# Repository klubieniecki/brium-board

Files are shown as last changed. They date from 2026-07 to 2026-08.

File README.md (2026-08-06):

<p align="center">
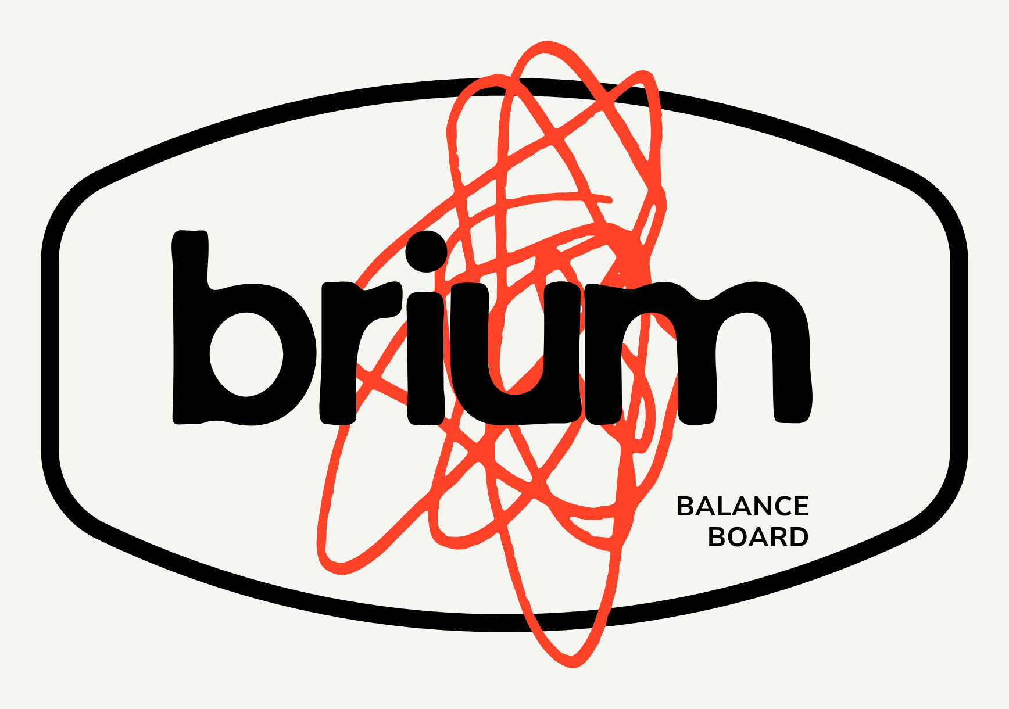
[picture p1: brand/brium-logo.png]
Brium Board
  
</p>

# Brium Board

*Brium* — the tail of *equilibrium*.

A rocker-style balance board and stand, cut from a **single 2 ft × 2 ft plywood
sheet** (610 × 610 mm), balanced on a lacrosse ball.

The board profile, the stand and the ball guard all come from **[dtxtr's
"Balance Board Stand (board and ball)"](https://www.printables.com/model/1341613-balance-board-stand-board-and-ball)**
on Printables. What this repo adds is the piece that model doesn't include: a
**3D-printed stencil** that lays the cut line out on your plywood — correctly
scaled to a 2×2 sheet, symmetric by construction, and drawn from one printed
template that works at all four corners.

<!-- IMAGE still needed: hero shot — finished board on the stand, ball underneath,
     good light. When shot, save as docs/images/finished-board.jpg and restore:
![The finished Brium board](docs/images/finished-board.jpg) -->

---

## What you make

| Part | Material | Source |
| --- | --- | --- |
| Brium board | 12 mm plywood, 360 × 610 mm | cut it yourself — **this repo's stencil** |
| Stand | 3D printed | `stl/brium_stand.stl` — remixed from [dtxtr's design](https://www.printables.com/model/1341613-balance-board-stand-board-and-ball) |
| Ball guard | 12 mm plywood | [dtxtr on Printables](https://www.printables.com/model/1341613-balance-board-stand-board-and-ball) — cut from the offcut |
| Ball | lacrosse ball | any sporting goods shop |

Everything printed here is a **jig**, not a part of the finished board. Once the
plywood is cut, the stencil's job is done.

---

## Bill of materials

| Item | Spec | Notes |
| --- | --- | --- |
| Plywood | 610 × 610 × 12 mm | 2 ft × 2 ft hobby panel. Birch ply is what the original used; void-free matters more than species |
| Lacrosse ball | [standard](https://www.amazon.ca/dp/B072373GWG), ~63 mm | solid rubber. Do not substitute a tennis ball |
| Filament | ~40 g for the stencil, ~150 g per stand piece | PLA is fine for both |
| 3 mm rod | 40 mm | joins the two stencil halves. A stub of 1.75 mm filament doubled over, an M3 bolt, or a brad nail all work |
| Sandpaper | 80 / 120 / 220 grit | |
| Finish | oil, poly or hardwax | your call |

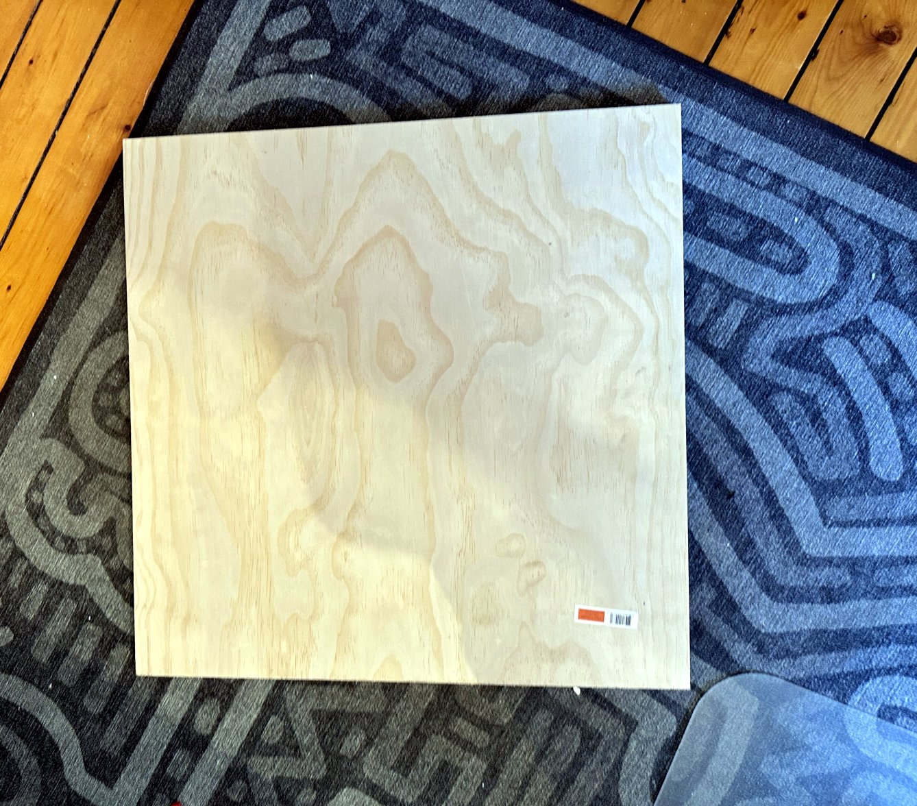
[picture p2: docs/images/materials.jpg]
The 610 × 610 sheet, before anything happens to it


---

## The cut

Your sheet is 610 × 610. Rip it once:

```
┌─────────────────────────── 610 ───────────────────────────┐
│                                                           │
│   BOARD          360 mm wide × 610 mm long                │  610
│                                                           │
├───────────────────────────────────────────────────────────┤
│   OFFCUT         250 mm × 610 mm  →  ball guard           │
└───────────────────────────────────────────────────────────┘
```

The board keeps the **full 610 mm length** of the sheet and gets ripped to
**360 mm wide**. The 250 mm offcut is more than enough for the ball guard.

The rounded outline is then laid out **inside** that 360 × 610 rectangle — it
touches all four edges, so you lose nothing to the curve.

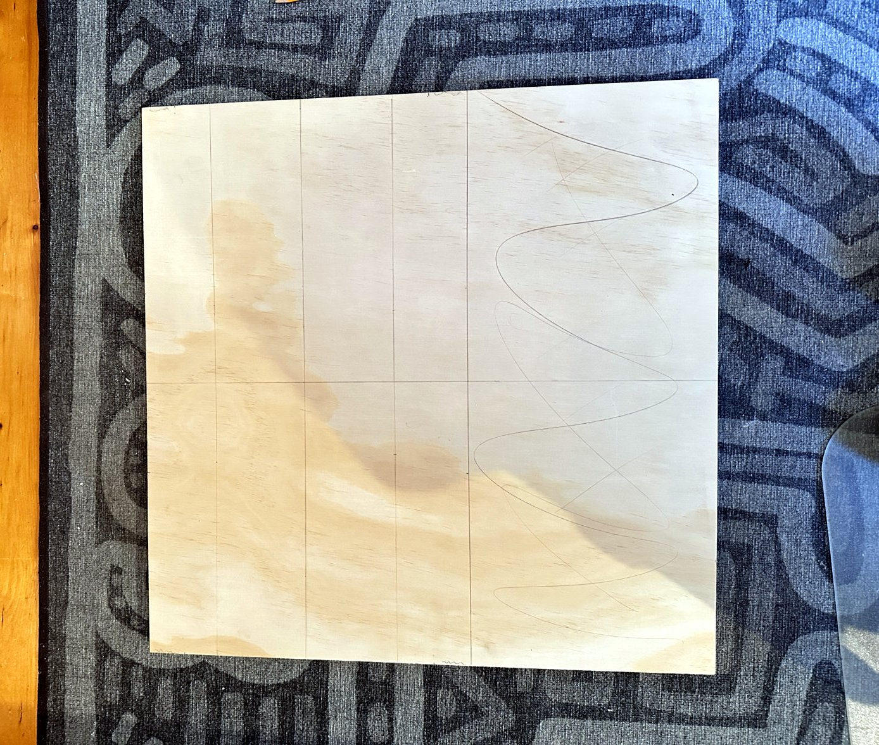
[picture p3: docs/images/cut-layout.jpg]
The sheet marked up — centrelines and layout before the rip cut


---

## The geometry

dtxtr's profile is a 540 × 310 outline built from four elements per side: a
straight flat on each short end, a tight corner radius, and one long sweep arc
down each side. Scaled to a 2×2 sheet:

| Element | dtxtr's original (540 × 310) | This build (610 × 360) |
| --- | --- | --- |
| Overall length | 540 mm | **610 mm** (full sheet) |
| Overall width | 310 mm | **360 mm** |
| Straight flat, each short end | 110 mm | **128 mm** |
| Corner radius | R50 | **R60** |
| Long sweep radius | R559 | **R623.94** |
| Sweep centre, below the long centreline | 404 mm | **443.94 mm** |
| Arcs meet tangent at | — | **(271.1, 118.0)** |

The sweep radius is **not a free choice.** It is solved so the long arc is
tangent to the corner arc *and* peaks exactly on the board edge at mid-length:

```
R = ( (L − rc)² + (W − a)² − rc² ) / ( 2 · (W − a − rc) )

L  = 305   half length        a  = 64   half the end flat
W  = 180   half width         rc =  60   corner radius
```

That is what keeps the outline fair — no visible kink where the corner meets
the sweep. Change the end flat or the corner radius in the .scad and the sweep
re-solves itself.

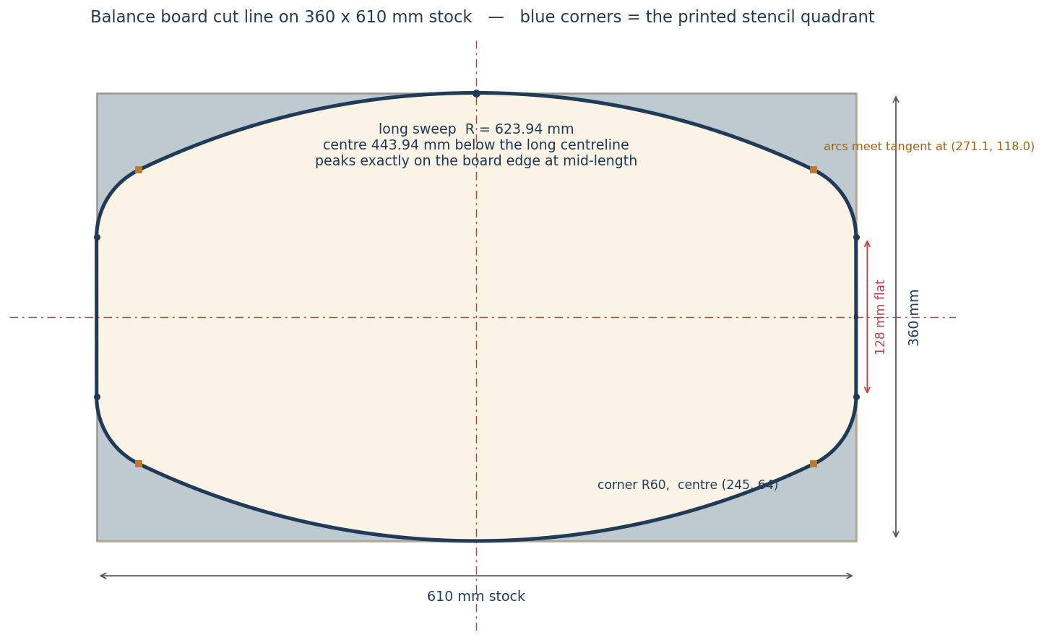
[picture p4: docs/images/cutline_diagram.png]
Cut line on a 360 × 610 sheet


---

## The stencil

The printed part is the **waste crescent** between the board corner and the cut
line — the material you're about to remove. It's a rib frame: a 9 mm rib
hugging the cut line (the edge you trace against), a 6 mm flange along each
board edge, and three cross ribs.

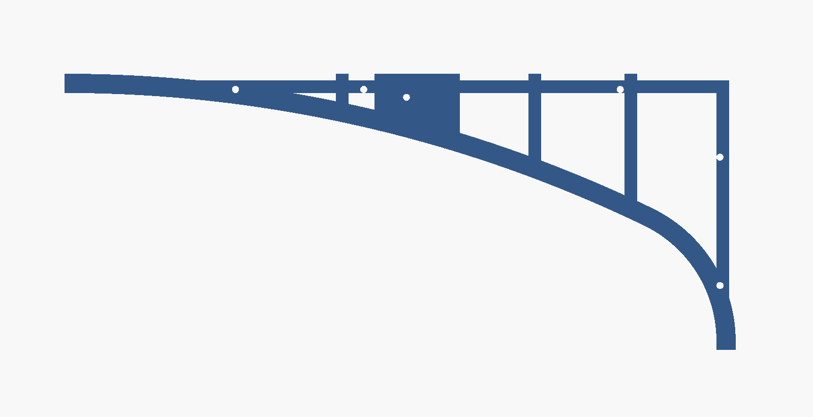
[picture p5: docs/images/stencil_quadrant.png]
Stencil quadrant


### One template, four corners

The outline is symmetric about both centrelines, so the *shape* at every corner
is identical. A quadrant isn't mirror-symmetric though — two corners want it
left-handed, two want it right-handed. A flat part handles that by flipping
over, so the stencil registers **both ways up**:

| Corner | Orientation | How it locates |
| --- | --- | --- |
| top-right | lip down | flanges hook the plywood corner |
| bottom-left | lip down, rotated 180° | same |
| top-left | flipped, lip up | pegs dropped into the flange holes |
| bottom-right | flipped, rotated 180° | same |

**Lip down** — the flanges hang 6 mm past the board edges and drop 3 mm. Seat
it on a corner and it hooks both edges. It can only sit in one place.

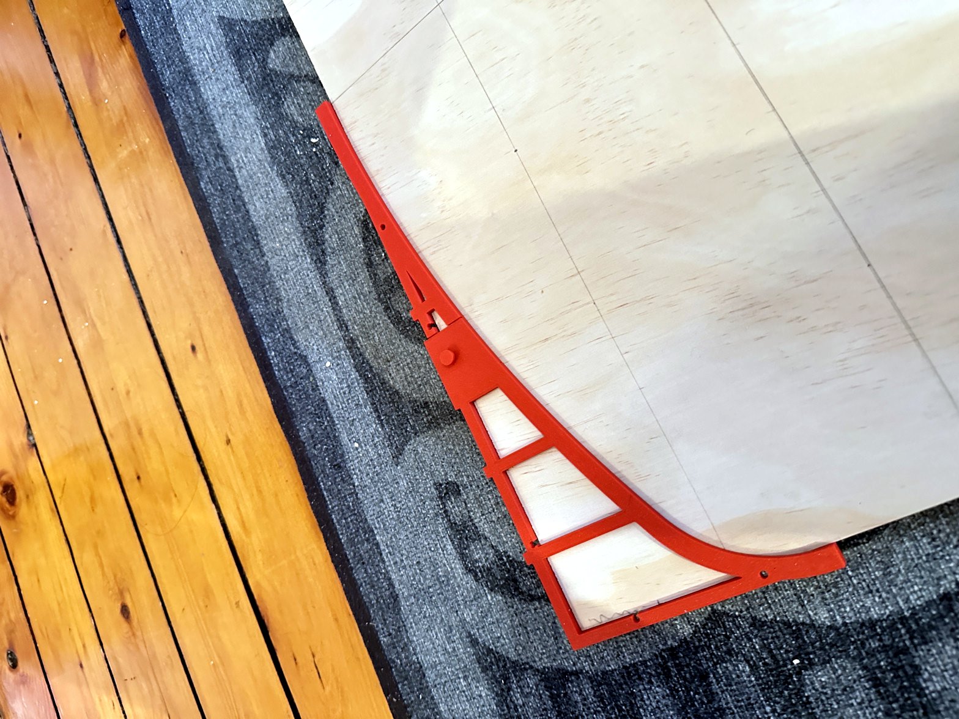
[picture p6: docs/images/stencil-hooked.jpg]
Lip down, hooked over the plywood corner


**Flipped** — the lip now faces up and hooks nothing, so five loose pegs take
over. Their holes are placed so the **inner tangent of the peg sits exactly on
the board edge line**, and a through-hole is symmetric about the plate's
mid-plane, so the registration survives the flip.

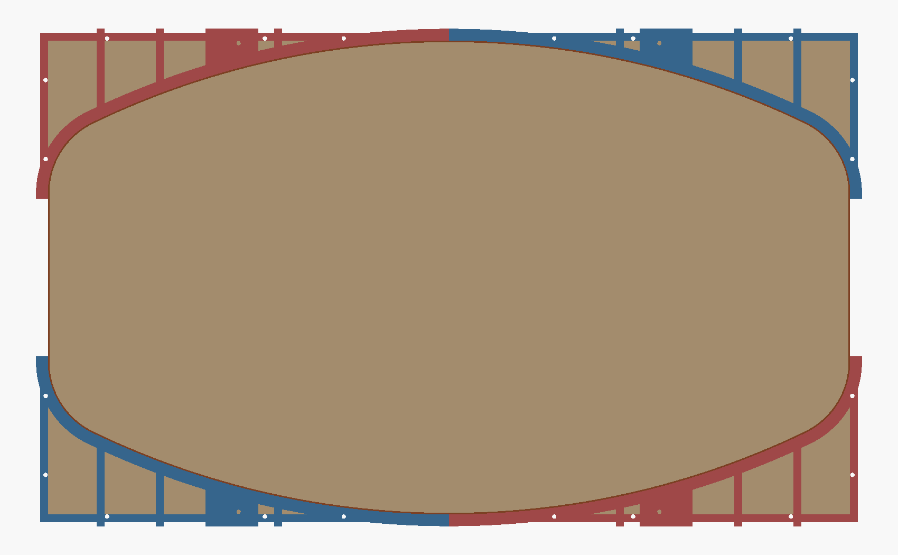
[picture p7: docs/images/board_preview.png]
All four corners


### Using it

1. Mark both centrelines on the plywood — mid-length and mid-width.
2. Lip down, hook the stencil over a corner, both flanges hard against the
   edges. **Check:** the straight edge at the mid-length end should land on your
   centreline. If it does, the geometry is right.
3. Trace the inner curved edge.
4. Rotate 180° for the opposite corner.
5. Flip the stencil, press the pegs in, seat them against the board edges, and
   do the remaining two corners.
6. The short ends need no tracing — the cut line runs along the existing edge
   for 128 mm before it curves away.

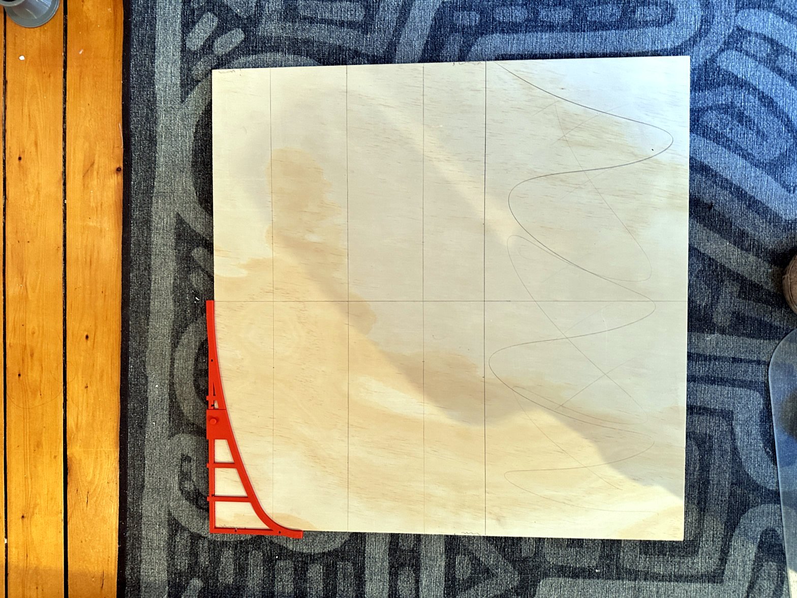
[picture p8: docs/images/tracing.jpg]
The stencil seated on a corner, ready to trace


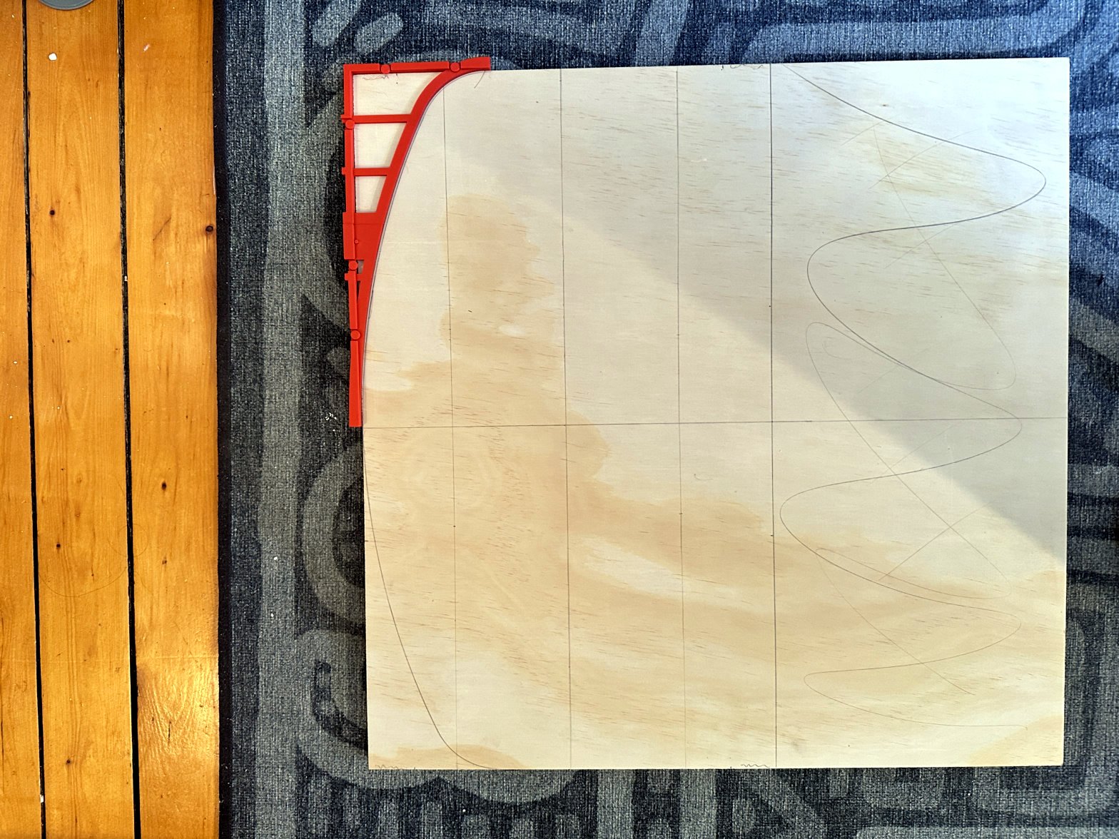
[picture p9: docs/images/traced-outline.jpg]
Flipped for the opposite-handed corners, outline taking shape


### Cutting and finishing

Jigsaw or bandsaw just outside the line, then sand back to it. A spindle sander
or a drum in a drill press makes short work of the R60 corners. Round the top
edges over with a 3–6 mm roundover or just break them with 120 grit — you'll be
standing on this barefoot.

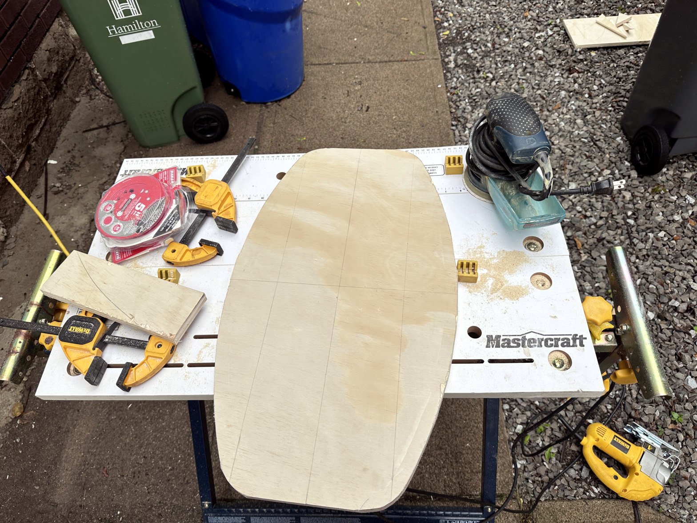
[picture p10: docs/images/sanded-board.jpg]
Cut and sanded, before finish


---

## Printing

### The stencil (this repo)

| File | Size | Notes |
| --- | --- | --- |
| `stl/brium_stencil_end.stl` | 169 × 129 × 7 mm | corner half — the R60 and most of the sweep |
| `stl/brium_stencil_mid.stl` | 175 × 34 × 7 mm | reaches the board's mid-length |
| `stl/brium_stencil_pegs.stl` | 8 pegs | print a couple spare |
| `brium_stencil.3mf` | — | ready-to-slice Bambu Studio project, all plates set up |

Flat on the bed, **no supports**. The plate prints first and the lip rail on
top of it, so nothing overhangs — flip each piece over to use it. Pegs print
head-down. Everything fits a 180 mm bed.

The two halves join with a half-lap and a 3 mm pin. Glue is optional; the pin
plus the lap is enough for a jig.

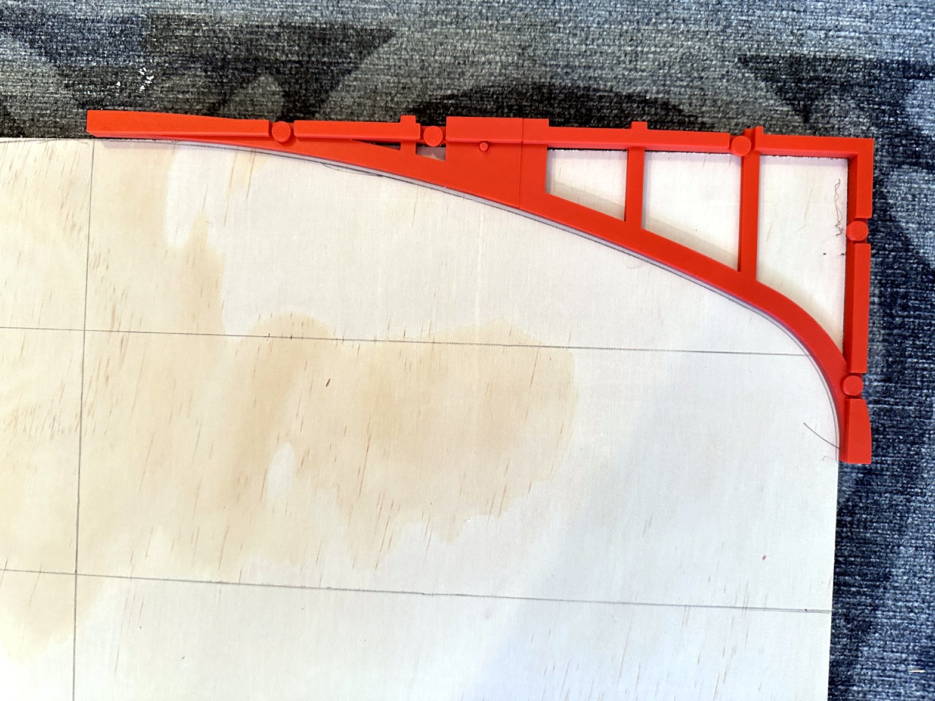
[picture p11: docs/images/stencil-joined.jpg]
Both halves joined, sitting on the traced line


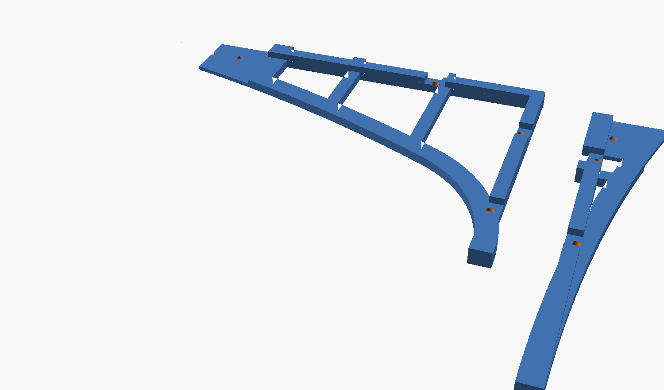
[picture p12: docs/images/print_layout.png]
Print layout


### The stand

**A remix of [dtxtr's stand](https://www.printables.com/model/1341613-balance-board-stand-board-and-ball)**,
modified to suit this build. His original is the design; this is a derivative
of it — go download and like his model too.

| File | Size | Notes |
| --- | --- | --- |
| `stl/brium_stand.stl` | 103 × 130 × 24 mm | one stand piece — print two |
| `brium_stand.3mf` | — | Bambu Studio project, sliced for a P1S |

125 cm³ of geometry, so budget roughly 150 g of filament per piece. The 3mf is
set up at 0.2 mm layers, 2 walls, 15 % infill, **no supports**, auto brim.

The stand is sized for 12 mm board stock — keep your plywood at 12 mm or adjust
the model to suit.

### The ball guard

Plywood, not printed — cut it from the 250 mm offcut. Dimensions are on
[dtxtr's page](https://www.printables.com/model/1341613-balance-board-stand-board-and-ball).

### The original Rola parts

Further up the family tree sits
**[whitespring's "Balance board pattern and parts"](https://www.printables.com/model/926271-balance-board-pattern-and-parts)**.
Their `Rola_Parts-v2.3mf` (two printed parts, ready-sliced in PrusaSlicer) is
included unmodified in [`third_party/whitespring/`](third_party/whitespring/) —
see that folder's README and their Printables page for usage and licence.

They mount to the board's underside with threaded inserts and M-screws:

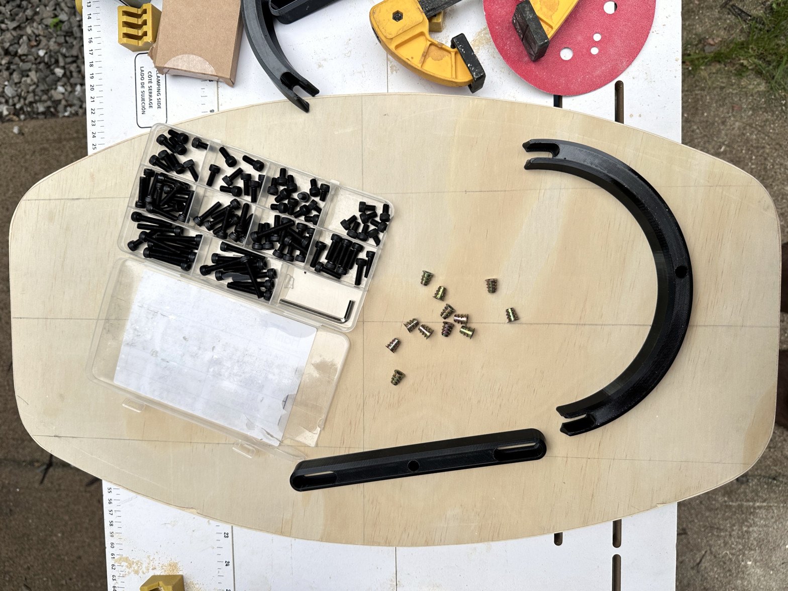
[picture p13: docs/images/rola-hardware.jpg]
Inserts, screws and the printed Rola parts


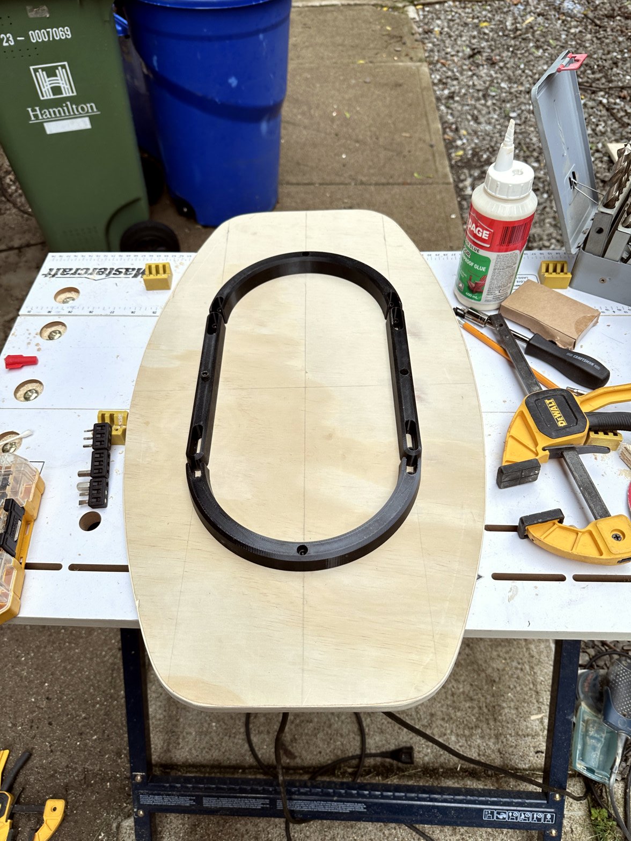
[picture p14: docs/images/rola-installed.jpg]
The Rola guard track installed on the underside


---

## Customising

Everything lives in `brium_stencil.scad`. Open it in
[OpenSCAD](https://openscad.org/), or use Window → Customizer for a form.

| Parameter | Default | Effect |
| --- | --- | --- |
| `BOARD_LEN` / `BOARD_WID` | 610 / 360 | your stock size — everything re-solves |
| `END_FLAT` | 128 | longer flat = squarer ends, flatter sweep |
| `CORNER_R` | 60 | tighter corners = more aggressive nose |
| `OVERHANG` / `LIP_T` | 6 / 3 | flange width past the edge, and lip depth |
| `PEGS` | true | peg holes for the flipped orientation |
| `TRACE_RIB` / `RIB_W` / `RIB_X` | 9 / 6 / 3 ribs | frame proportions |
| `PLATE_T` | 4 | plate thickness |
| `SPLIT_X` | 175 | where the two halves meet — lower it for a small bed |
| `PENCIL_COMP` | 0 | set to your pencil-tip radius (~0.7) so the drawn line lands on the true curve |
| `LIGHTEN` | true | rib frame vs solid crescent |

Re-export with:

```bash
./export_stl.sh
```

On macOS the OpenSCAD binary is inside the app bundle, which the script handles.
Set `PART` to `print_end`, `print_mid` or `pegs` if you'd rather export by hand
— **not** `assembly`, which is the two halves mated at 319 mm.

Deeper notes on the geometry, the joint and the mesh gotchas are in
[`docs/stencil.md`](docs/stencil.md).

---

## Repo layout

```
brium_stencil.scad     the parametric source — everything comes from here
export_stl.sh                  regenerates all three STLs
brium_stencil.3mf      Bambu Studio project, ready to slice
stl/                           exported meshes
third_party/whitespring/       whitespring's original Rola parts, unmodified
docs/stencil.md                design notes: geometry, joint, mesh validation
docs/images/                   renders and build photos
site/                          the landing site (Next.js, deploys on Vercel)
```

---

## Credits

- **[whitespring](https://www.printables.com/@whitespring)** — the
  [Balance board pattern and parts](https://www.printables.com/model/926271-balance-board-pattern-and-parts)
  ("Rola") that this whole family of boards traces back to. Their printed Rola
  parts are included unmodified in
  [`third_party/whitespring/`](third_party/whitespring/) — go like the
  original.
- **[dtxtr](https://www.printables.com/@dtxtr_339032)** — the original
  [Balance Board Stand (board and ball)](https://www.printables.com/model/1341613-balance-board-stand-board-and-ball).
  The board profile, the stand and the ball guard are all his design. This repo
  re-derives his outline for a different sheet size, wraps it in a layout jig,
  and includes a modified version of his stand. If you build this, go give his
  model a like first.
- Brium stencil design and OpenSCAD source:
  **[@klubieniecki](https://github.com/klubieniecki)**

## License

<!-- Pick one and delete the rest. CC BY-SA 4.0 is the usual choice for
     printable models and keeps you compatible with the remix culture on
     Printables/MakerWorld. -->

The OpenSCAD source and the exported **stencil** files in this repo are released
under **CC BY-SA 4.0**.

`brium_stand.stl` / `brium_stand.3mf` are a **derivative of dtxtr's stand**, not
original work. Before publishing this repo or a listing, check that his licence
permits derivatives and redistribution, and match whatever terms he set.

Everything under `third_party/` is **other people's work, included unmodified**
(currently whitespring's Rola parts) and is *not* covered by this repo's
licence — the terms on each original model page apply.

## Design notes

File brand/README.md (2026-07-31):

# Brium Board — brand assets

## Logo

`brium-logo.png` is the logo. The badge outline is the **real board profile** —
the same 610 × 360 cut line the stencil draws, at 12 px weight.

| File | Use |
| --- | --- |
| `brium-logo.png` | primary — README header, listings, print |
| `brium-logo-square.png` | same logo on a square canvas — avatars, thumbnails |
| `brium-logo-transparent.png` | background knocked out |

The logo is **raster**. That's fine for GitHub, MakerWorld and Printables, but
if you ever need it large-format or laser-engraved you'll want it as vector —
the badge outline below is already vector, so it's only the type and the
scribble that would need redrawing.

The type and the scribble are black, so **the transparent version needs a light
background**. On dark it disappears. Use the light background version, or
recolour before you put it on anything dark.

## Board outline

The bare cut-line shape, black stroke, no fill. This is what the badge in the
logo is built from.

| File | Weight |
| --- | --- |
| `brium-board-outline-3px.svg` | hairline |
| `brium-board-outline-5px.svg` | light |
| `brium-board-outline-8px.svg` | medium |
| `brium-board-outline-10px.svg` | heavy |
| `brium-board-outline-12px.svg` | heaviest — the weight used in the logo |

Coordinates are **1 unit = 1 mm**, so the SVG is natively 610 × 360 and
dimensionally accurate. Generated by `outline.py` — add any weight you want to
the tuple and re-run.

Note the stroke straddles the path, so at 12 px the drawn shape reads ~6 px
larger on every side than the true cut line. Don't trace one of these at 1:1;
that's what the stencil is for.

## Palette

| | Hex | Use |
| --- | --- | --- |
| Ink | `#000000` | outline, wordmark |
| Flare | `#FF4A24` | the scribble |
| Paper | `#F6F5EF` | background |

## Earlier exploration

`brium-mark*.svg`, `brium-avatar*.svg`, `brium-wordmark.svg` and
`brium-logo-horizontal/stacked.svg` are an earlier direction — the board
silhouette crossing a sun, generated by `build.py`. Superseded by the logo
above, kept in case any of it is useful for stickers or a secondary mark.

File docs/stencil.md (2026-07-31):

# Brium Board — stencil design notes

> Build guide and materials list: [../README.md](../README.md)

A parametric OpenSCAD stencil for laying out the rounded cut line of a balance
board on **360 × 610 mm** plywood (36 × 61 cm), derived from the Printables
["Balance Board Stand Board and Ball"](https://www.printables.com/model/1341613-balance-board-stand-board-and-ball)
sketch.

One printed quadrant marks all four corners.

---

## The geometry

The reference sketch is a 540 × 310 outline built from four elements per side:

| Element | Reference (540 × 310) | Yours (610 × 360) |
| --- | --- | --- |
| Overall length | 540 mm | **610 mm** (full stock) |
| Overall width | 310 mm | **360 mm** (full stock) |
| Straight flat on each short end | 110 mm | **128 mm** |
| Corner radius | R50 | **R60** |
| Long-side sweep radius | R559 (solved) | **R623.94 (solved)** |
| Sweep centre, below the long centreline | 404 mm | **443.94 mm** |
| Arcs meet tangent at | (271.1, 118.0) equivalent | **(271.1, 118.0)** |

The sweep radius is not a free choice. It is solved so the long arc is
simultaneously **tangent to the corner arc** and **peaks exactly on the board
edge at mid-length**:

```
R = ( (L - rc)² + (W - a)² - rc² ) / ( 2 · (W - a - rc) )

L  = 305  half length          a  = 64  half the end flat
W  = 180  half width           rc =  60  corner radius
```

That single formula is what keeps the whole outline smooth — no visible kink
where the corner meets the long sweep. Change `END_FLAT` or `CORNER_R` in the
.scad and the sweep re-solves itself.

Origin is the centre of the board. The cut line leaves the short end edge at
**y = ±64 mm** and touches the long edge at **x = 0**.

---

## How the stencil works

The printed part is the *waste crescent* between the board corner and the cut
line — the material you will be cutting away.

Trace along the inner curved edge.

### Registration — and why one template does all four corners

The outline is symmetric about both centrelines, so the *shape* at every corner
is the same. But a quadrant is not mirror-symmetric: two corners want it
left-handed, two want it right-handed. A flat part handles that — you flip it
over. The only thing that can break the flip is a feature living on one face,
which is exactly what a moulded lip is. So the template carries both:

| Corner | Orientation | Registration |
| --- | --- | --- |
| top-right | lip down | flanges hook the plywood corner |
| bottom-left | lip down, rotated 180° | same |
| top-left | flipped (lip up) | drop pegs into the flange holes |
| bottom-right | flipped, rotated 180° | same |

**Lip down** — the flanges hang 6 mm past the board edges and drop 3 mm. Seat
it on the corner and it hooks both edges; it can't sit anywhere else. No
measuring, no squaring up.

**Flipped** — the lip now faces up and hooks nothing, so the pegs take over.
Their holes are positioned so the **inner tangent of the peg lies exactly on
the board edge line**. A through-hole is symmetric about the plate's
mid-plane, so this survives the flip. Five holes: three along the long edge
(x = 80, 140, 260) and two along the short end (y = 90, 150). Three would
locate it; five means you can skip one if a clamp is in the way.

The lip is interrupted by a 10 mm gap at each peg hole — partly so the hole
isn't tangent to the lip's inner face (that made the export non-manifold),
partly to give the peg head somewhere flat to sit.

### Filament

A rib frame, not a solid plate: a 9 mm rib hugging the cut line, a 6 mm flange
strip along each board edge, three cross ribs, and a solid patch at the joint.
Everything else is open.

| | Solid, lipped, 15 mm flange | Lean rib frame |
| --- | --- | --- |
| Corner piece | 74.3 cm³ | **20.7 cm³** |
| Mid piece | 25.7 cm³ | **11.9 cm³** |
| 8 pegs | — | **1.2 cm³** |
| Copies needed for 4 corners | 2 (one mirrored) | **1** |
| **Total** | **200 cm³** | **33.8 cm³** (−83%) |

Ribs only pay where the frame is actually open. Below about x = 105 the trace
rib and the flange merge into one bar, so ribs there were doing nothing — the
count went 5 → 3 for that reason, not to shave grams.

Levers if you want less still: `TRACE_RIB` 9 → 8 (−1.5 cm³, but the pencil
edge gets narrow), `PLATE_T` 4 → 3.5 (the half-lap tongue is already only
1.8 mm — I would not). `LIGHTEN = false` goes back to the solid crescent.

### Printing

The quadrant is 319 × 129 mm, so it is half-lapped into two pieces that pin
together with a 3 mm rod (or a stub of filament) through the joint.

| Piece | Size | Notes |
| --- | --- | --- |
| `print_end` | 169 × 129 × 7 mm | the corner half, does the R60 and most of the sweep |
| `print_mid` | 175 × 34 × 7 mm | the thin half that reaches the board's mid-length |
| `pegs` | 8 buttons, 44 × 20 | registration pegs, print a couple spare |

Print **flat on the bed, no supports** — the plate goes down first and the lip
rail prints on top of it, so nothing overhangs. Flip each piece over to use it.
Pegs print head-down. Everything fits a 180 mm bed.

Do not export `PART = "assembly"` — that is the two pieces mated, 319 mm long.

#### Exporting the STLs

`./export_stl.sh` writes the whole print set to `stl/` as binary STLs:

| File | What it is |
| --- | --- |
| `brium_stencil_end.stl` | the corner half of the template |
| `brium_stencil_mid.stl` | the half that reaches the board's mid-length |
| `brium_stencil_pegs.stl` | 8 registration pegs |

Three prints, all four corners. All watertight, single-body, correct winding —
Bambu Studio imports them without a repair prompt. Or by hand: set `PART` to
`print_end` / `print_mid` / `pegs`, F6, then File → Export → Export as STL.

For a 180 mm bed, raise `FLANGE_Y0` (currently 30) to about 60, or move
`SPLIT_X` down to ~155.

Render targets (`PART = ...`):

| Value | Shows |
| --- | --- |
| `assembly` | both pieces joined — the full quadrant |
| `print_end` / `print_mid` | one piece, ready to export as STL |
| `print_all` | both laid out for a 220 × 220 bed |
| `board_preview` | the stock, the cut line, and all four stencils in place |
| `outline_only` | the raw 2D cut line (export as DXF/SVG for a 1:1 paper template) |

### Using it

1. Mark the two centrelines on the plywood (mid-length and mid-width).
2. Lip down, hook the template over a corner — both flanges hard against the
   board edges. The straight edge at the mid-length end should land on your
   centreline; that is your check that the geometry is right.
3. Trace the inner curve. Set `PENCIL_COMP` to your pencil-tip radius
   (≈ 0.7 mm) if you want the drawn line to land dead on the true curve.
4. Rotate 180° for the opposite corner. For the remaining two, flip the
   template over, press the pegs in, and seat them against the board edges.
5. The short ends are already straight — the cut line runs along the existing
   edge for 128 mm before it curves away.

---

## Parameters worth touching

| Parameter | Default | Effect |
| --- | --- | --- |
| `END_FLAT` | 128 | longer flat = squarer ends, flatter sweep |
| `CORNER_R` | 60 | tighter corners = more aggressive nose |
| `OVERHANG` / `LIP_T` | 6 / 3 | flange width past the edge, and lip depth |
| `PEGS` | true | peg holes for the flipped orientation |
| `TRACE_RIB` / `RIB_W` / `RIB_X` | 9 / 6 / 3 ribs | frame proportions |
| `PEG_X` / `PEG_Y` | lists | where the registration pegs sit |
| `LIGHTEN` | true | rib frame instead of a solid crescent |
| `PLATE_T` | 4 | plate thickness |
| `SPLIT_X` | 175 | where the two pieces meet |
| `PENCIL_COMP` | 0 | grows the curve by the pencil-tip radius |
| `MIRROR` | false | mirrored copy for the other two corners |

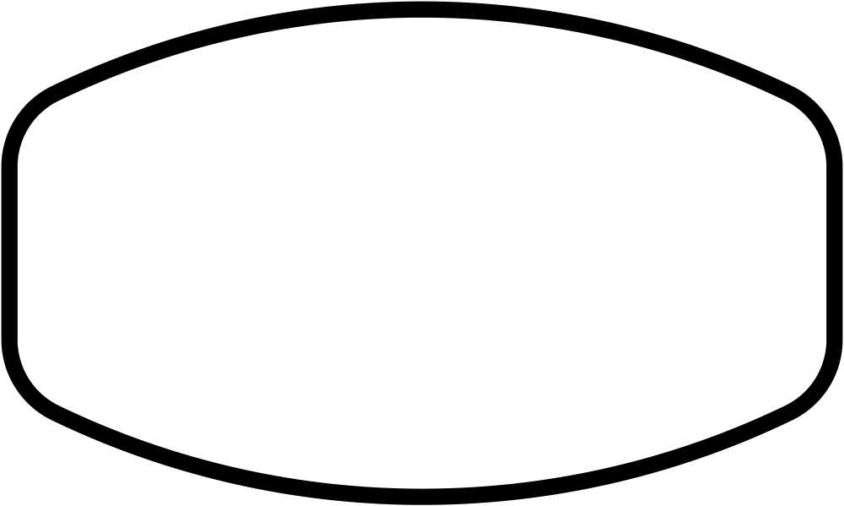
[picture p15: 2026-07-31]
brand/brium-board-outline-12px.png

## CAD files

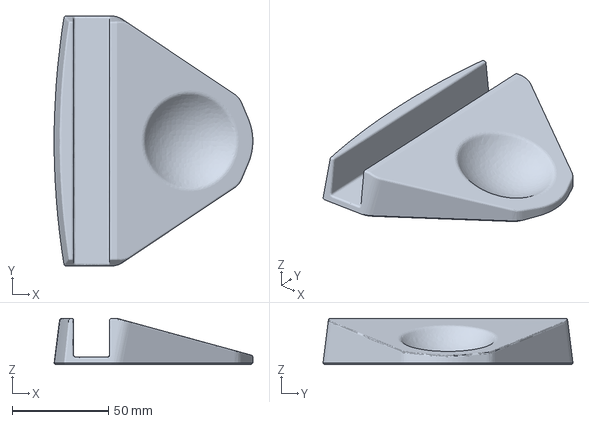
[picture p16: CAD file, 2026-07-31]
brium_stand.3mf
103.2 x 129.8 x 24.0 mm

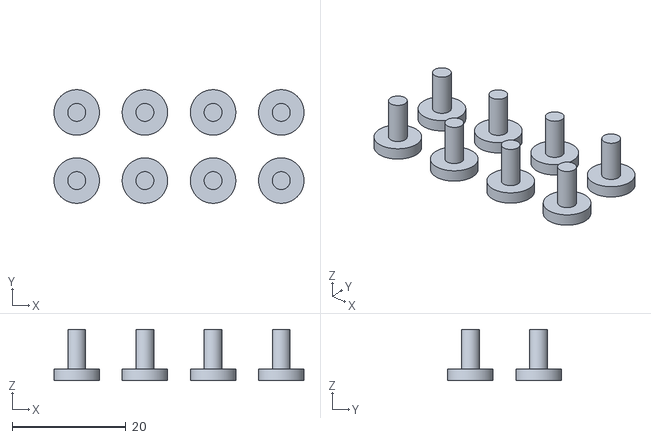
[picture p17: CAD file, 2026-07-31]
stl/brium_stencil_pegs.stl
44.0 x 20.0 x 9.00

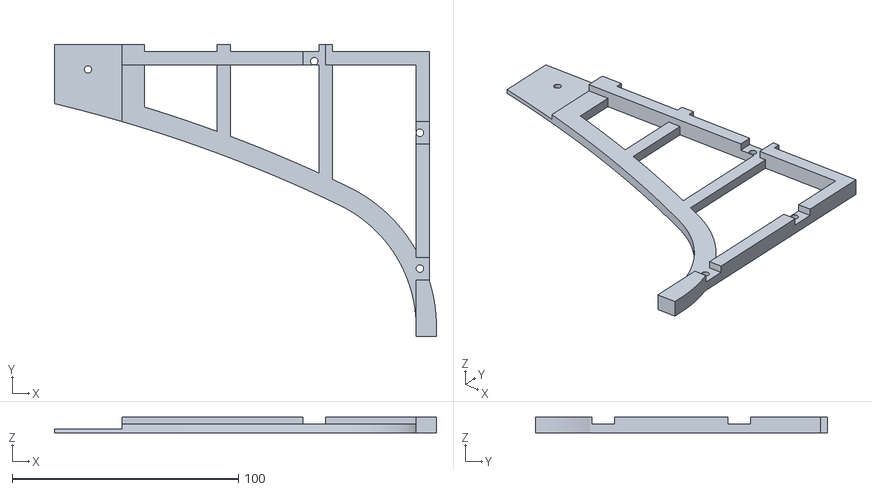
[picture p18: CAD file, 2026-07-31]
stl/brium_stencil_end.stl
168.8 x 129.0 x 7.00

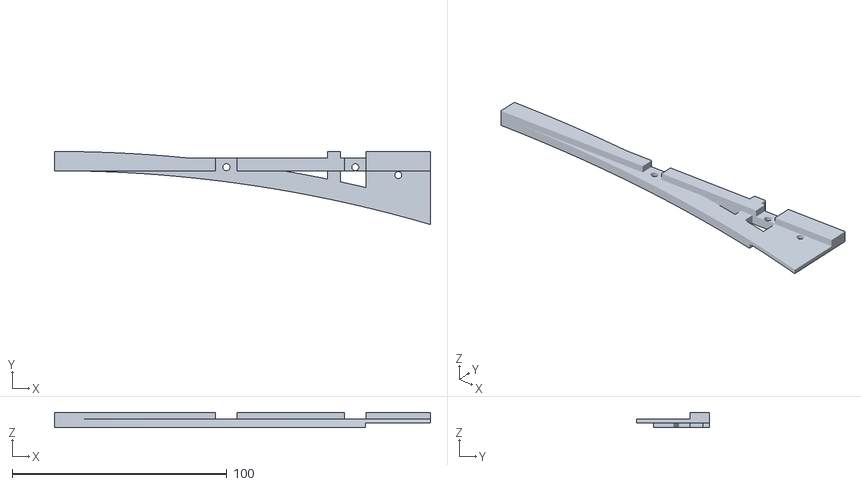
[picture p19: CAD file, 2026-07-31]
stl/brium_stencil_mid.stl
175.0 x 34.0 x 7.00

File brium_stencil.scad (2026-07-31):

// =====================================================================
// Brium Board - outline stencil, ONE QUADRANT, all four corners
// ---------------------------------------------------------------------
// Stock       : 360 mm x 610 mm plywood (36 cm x 61 cm)
// Shape source: Printables "Balance Board / Stand Board and Ball"
//               sketch = 540 x 310, 110 mm end flat, R50 corners.
//               Re-solved here so the cut line touches all four edges
//               of YOUR board and stays tangent everywhere.
//
// The stencil is a rib frame sitting in the WASTE crescent between the board
// corner and the cut line. Trace the inner curved edge.
//
// Registration, two corners at a time:
//
//   Lip down  - the flanges hang 6 mm past the board edges and drop 3 mm, so
//               the template hooks the plywood corner and cannot sit anywhere
//               else. Covers corner (+,+) and, rotated 180 deg, (-,-).
//   Flipped   - the lip now faces up and cannot hook anything, so drop loose
//               pegs into the flange holes instead. Their inner tangent lies
//               exactly on the board edge line, and a through hole is
//               symmetric about the plate's mid-plane, so the registration
//               survives the flip. Covers the other two corners.
//
// One template, four corners, no mirrored second copy.
// =====================================================================

$fn = 200;

/* [Board] */
BOARD_LEN   = 610;   // long dimension of the plywood (mm)
BOARD_WID   = 360;   // short dimension of the plywood (mm)
END_FLAT    = 128;   // straight run left on each short end (mm)
CORNER_R    = 60;    // radius of the four tight corners (mm)

/* [Stencil body] */
OVERHANG    = 6;     // flange width past the board edge
FLANGE_Y0   = 60;    // end-edge flange starts here (raise for a smaller bed)
PLATE_T     = 4;     // plate thickness
LIP_T       = 3;     // how far the flange drops over the board edge (0 = flat plate)
MIRROR      = false; // true -> mirrored copy for the other two corners
PENCIL_COMP = 0;     // pencil-tip radius, e.g. 0.7 -> line lands on the true curve

/* [Lightening] */
LIGHTEN     = true;  // false -> old solid crescent
TRACE_RIB   = 9;     // width of the rib that hugs the cut line
RIB_W       = 6;     // width of the cross ribs
RIB_X       = [130, 220, 265];  // where the cross ribs sit

/* [Reversible registration] */
PEGS        = true;  // peg holes for the flipped orientation, where the lip
                     // faces up and cannot hook the board
PEG_D       = 3.3;   // peg hole dia; inner tangent sits on the board edge
PEG_X       = [80, 140, 260];  // peg holes along the long edge
PEG_Y       = [90, 150];       // peg holes along the short end edge
PEG_HEAD_D  = 8;     // peg head
PEG_HEAD_T  = 2;
PEG_STAND   = 3;     // how far the peg stands proud on the underside
PEG_FIT     = 0.15;  // shaft undersize for a press fit
PEG_NOTCH   = 10;    // width of the gap cut in the lip at each peg hole
PEG_COUNT   = 8;     // how many to lay out in PART = "pegs"

/* [Splitting for the print bed] */
SPLIT       = true;  // half-lap the quadrant into two printable pieces
SPLIT_X     = 175;   // joint position, measured from board centre
LAP_LEN     = 30;    // half-lap overlap length
LAP_TOL     = 0.2;   // fit clearance
JOINT_PAD   = 10;    // how far the solid joint patch runs past the split plane
PIN_D       = 3.2;   // vertical alignment pin (3 mm filament / M3 rod)
PIN_Y       = 178;   // where the pin goes

/* [What to render] */
// assembly | print_end | print_mid | pegs | print_all | board_preview | outline_only
PART        = "assembly";

// ---------------------------------------------------------------------
// derived geometry
// ---------------------------------------------------------------------
L  = BOARD_LEN / 2;   // 305  half length
W  = BOARD_WID / 2;   // 180  half width
A  = END_FLAT  / 2;   //  64  half of the straight end run
RC = CORNER_R;

// Long-side sweep radius, solved so that arc is tangent to the corner
// arc AND peaks exactly on the board edge at mid-length.
SWEEP_R = (pow(L - RC, 2) + pow(W - A, 2) - pow(RC, 2)) / (2 * (W - A - RC));
CY      = W - SWEEP_R;                  // sweep centre (well below the board)
CCX     = L - RC;                       // corner arc centre
CCY     = A;
THETA_T = atan2(CCY - CY, CCX);         // tangent angle, measured at the sweep centre
TX      = SWEEP_R * cos(THETA_T);
TY      = CY + SWEEP_R * sin(THETA_T);

echo(str("--- cut line ---"));
echo(str("sweep radius R  = ", SWEEP_R, " mm   centre [0, ", CY, "]"));
echo(str("corner arc      = R", RC, " centre [", CCX, ", ", CCY, "]"));
echo(str("tangent point   = [", TX, ", ", TY, "]"));
echo(str("line leaves the end edge at y = +/-", A));

STEPS = 120;

// quarter of the cut line: (L,0) -> (L,A) -> R60 arc -> sweep arc -> (0,W)
// o > 0 grows the shape outward (pencil compensation)
function quarter(o = 0) = concat(
    [[L + o, 0]],
    [ for (i = [0 : STEPS])
        let (t = THETA_T * i / STEPS)
        [CCX + (RC + o) * cos(t), CCY + (RC + o) * sin(t)] ],
    [ for (i = [1 : STEPS])
        let (t = THETA_T + (90 - THETA_T) * i / STEPS)
        [(SWEEP_R + o) * cos(t), CY + (SWEEP_R + o) * sin(t)] ]
);

function outline_pts(o = 0) =
    let (q = quarter(o), n = len(q))
    concat(
        q,
        [ for (i = [n - 2 : -1 : 1]) [-q[i][0],  q[i][1]] ],
        [ for (i = [0 : n - 1])      [-q[i][0], -q[i][1]] ],
        [ for (i = [n - 2 : -1 : 1]) [ q[i][0], -q[i][1]] ]
    );

module outline_2d(o = 0) { polygon(outline_pts(o)); }

// ---------------------------------------------------------------------
// stencil footprint
// ---------------------------------------------------------------------
PX1  = L + OVERHANG;                        // outer edge of the flanges
PY1  = W + OVERHANG;
CLX  = L + max(OVERHANG, TRACE_RIB);        // clip box: the trace rib is allowed
CLY  = W + max(OVERHANG, TRACE_RIB);        // to bulge past the flange where it must

module blank_2d()   { polygon([[0, FLANGE_Y0], [CLX, FLANGE_Y0], [CLX, CLY], [0, CLY]]); }
module onboard_2d() { polygon([[-1, -1], [L, -1], [L, W], [-1, W]]); }

// everything between the cut line and the clip box = the solid crescent
module crescent_2d() {
    difference() { blank_2d(); outline_2d(PENCIL_COMP); }
}

// --- the three things the lightened frame is made of ---------------------
// 1. a rib hugging the cut line - this is the edge you trace against
module trace_rib_2d() {
    intersection() {
        crescent_2d();
        difference() {
            offset(r = TRACE_RIB) outline_2d(PENCIL_COMP);
            outline_2d(PENCIL_COMP);
        }
    }
}
// 2. the two flange strips that hook the board edges
module flange_strips_2d() {
    intersection() {
        crescent_2d();
        union() {
            polygon([[L - 0.01, FLANGE_Y0], [PX1, FLANGE_Y0], [PX1, PY1], [L - 0.01, PY1]]);
            polygon([[0, W - 0.01], [PX1, W - 0.01], [PX1, PY1], [0, PY1]]);
        }
    }
}
// 3. cross ribs tying the two together, plus a solid patch at the joint
module cross_ribs_2d() {
    intersection() {
        crescent_2d();
        union() {
            for (x = RIB_X)
                polygon([[x - RIB_W / 2, -99], [x + RIB_W / 2, -99],
                         [x + RIB_W / 2, 999], [x - RIB_W / 2, 999]]);
            // solid patch straddling the joint: it must continue past the
            // split plane, or the cross-section steps there and the exported
            // mesh picks up T-junctions
            if (SPLIT)
                polygon([[SPLIT_X - LAP_LEN, -99], [SPLIT_X + JOINT_PAD, -99],
                         [SPLIT_X + JOINT_PAD, 999], [SPLIT_X - LAP_LEN, 999]]);
        }
    }
}

module plate_area_2d() {
    if (LIGHTEN) union() { trace_rib_2d(); flange_strips_2d(); cross_ribs_2d(); }
    else intersection() {
        crescent_2d();
        polygon([[0, FLANGE_Y0], [PX1, FLANGE_Y0], [PX1, PY1], [0, PY1]]);
    }
}

// the part hanging off the board = where the lip lives
module flange_area_2d() {
    difference() { blank_2d(); onboard_2d(); }
}

// ---------------------------------------------------------------------
// registration
// ---------------------------------------------------------------------
// REVERSIBLE mode: no moulded lip. Instead the flanges carry a row of
// through-holes whose INNER TANGENT lies exactly on the board edge line.
// Drop a peg in from whichever face is up and it sticks out 3 mm on the
// underside and butts the board edge. A through-hole is symmetric about the
// plate's mid-plane, so the part works either way up - one template, all
// four corners.
LIP = LIP_T;
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

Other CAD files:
stl/brium_stand.stl

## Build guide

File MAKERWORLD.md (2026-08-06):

# MakerWorld listing — copy/paste

Everything below is ready to paste. Replace `YOUR-GITHUB-USERNAME` throughout,
and drop in your photos where noted.

---

## Title

```
Brium Board — balance board layout stencil for one 2×2 plywood sheet
```

## Summary / tagline

```
Brium (from equilibrium). A 3D-printed jig that draws dtxtr's balance board profile onto a 610 × 610 mm plywood sheet. One template, all four corners, symmetric by construction.
```

## Tags

```
brium, balance board, wobble board, stencil, template, jig, woodworking, plywood, openscad, parametric, lacrosse ball, balance trainer, layout tool
```

## Category

Tools & Gadgets → Woodworking / Jigs

---

## Description

**Brium** — the tail end of *equilibrium*. Balance, minus the run-up.

**This is a layout jig, not the board itself.**

I wanted to build [dtxtr's balance board and
stand](https://www.printables.com/model/1341613-balance-board-stand-board-and-ball)
but I had a 2 ft × 2 ft plywood sheet — 610 × 610 mm — and his profile is drawn
for 540 × 310. Scaling a curve like that by eye doesn't work, and freehanding a
600 mm sweep arc symmetrically across four corners *really* doesn't work.

So I re-derived the profile for the larger sheet and made a stencil to draw it.

### What it does

Rip your 2×2 sheet down to **360 × 610 mm** and the stencil lays the full
rounded outline onto it. The profile touches all four edges of the blank, so you
use every millimetre of the sheet, and the 250 mm offcut is exactly enough for
the ball guard.

The printed part is the **waste crescent** between the board corner and the cut
line — the bit you're about to saw off. You trace along its inner edge.

### One template covers all four corners

The outline is symmetric about both centrelines, so the shape at every corner is
identical. The catch is handedness: two corners want it left-handed, two want it
right-handed. A flat part solves that by flipping over — the trick was making it
register **both ways up**.

- **Lip down** — the flanges hang 6 mm past the board edges and drop 3 mm. Seat
  it on a corner and it hooks both edges. It physically cannot sit anywhere
  else. That's two corners (rotate 180° for the second).
- **Flipped** — the lip now faces up and hooks nothing, so five loose pegs take
  over. Their holes are placed so the *inner tangent of the peg* sits exactly on
  the board edge line, and a through-hole is symmetric about the plate's
  mid-plane, so the registration survives the flip. That's the other two.

No mirrored second copy. No measuring. No squaring anything up.

### The geometry

The long sweep radius isn't a number I picked — it's solved so the arc is
tangent to the corner arc *and* peaks exactly on the board edge at mid-length:

```
R = ( (L − rc)² + (W − a)² − rc² ) / ( 2 · (W − a − rc) )
```

For a 610 × 360 board with a 128 mm end flat and R60 corners, that gives
**R = 623.94 mm**, centred 443.94 mm below the long centreline. That's what
keeps the outline fair — no kink where the corner meets the sweep.

The source is parametric OpenSCAD. Different sheet? Change two numbers and the
whole profile re-solves.

### What you print

| File | Size |
| --- | --- |
| `brium_stencil_end.stl` | 169 × 129 × 7 mm |
| `brium_stencil_mid.stl` | 175 × 34 × 7 mm |
| `brium_stencil_pegs.stl` | 8 pegs |

The two halves join with a half-lap and a 3 mm pin (a brad nail or a doubled
stub of filament works). About **34 cm³** of plastic for the whole set — roughly
40 g.

### Print settings

- **Flat on the bed, no supports.** The plate prints first and the lip rail on
  top of it, so nothing overhangs. Flip each piece over to use it.
- Pegs print head-down.
- 3 walls, 15 % infill, 0.2 mm layers. It's a jig — it wants stiffness, not
  strength.
- Fits a 180 mm bed.

A ready-to-slice `.3mf` is included with the plates already arranged.

### You'll also need

- The stand — a remix of **[dtxtr's
  original](https://www.printables.com/model/1341613-balance-board-stand-board-and-ball)**,
  included here as `brium_stand.stl`. Go download and like his model too.
- The ball guard — plywood, cut from your offcut; dimensions on his page
- 610 × 610 × 12 mm plywood (his stand is sized for 12 mm stock)
- A lacrosse ball
- A jigsaw or bandsaw, and something to sand the curve back to the line

---

## Credits

**The board profile, the stand and the ball guard are all
[dtxtr's](https://www.printables.com/@dtxtr_339032) work** —
["Balance Board Stand (board and ball)"](https://www.printables.com/model/1341613-balance-board-stand-board-and-ball).
All I did was re-derive his outline for a bigger sheet and build a jig to draw
it. If you make this, go like and follow his model first.

Further up the family tree:
**[whitespring's](https://www.printables.com/@whitespring)**
["Balance board pattern and parts"](https://www.printables.com/model/926271-balance-board-pattern-and-parts)
(the Rola). Their printed parts are included unmodified in the repo's
`third_party/whitespring/` folder — go like that one too.

Full build guide, the parametric OpenSCAD source, and the maths behind the
sweep radius:
**https://github.com/klubieniecki/brium-board**

Remixes welcome — the source is CC BY-SA 4.0. If you adapt it for a different
sheet size, post a make and tell me the numbers you used.

---

## Photos to upload (in this order)

1. Finished Brium board on the stand — the money shot, this becomes the
   thumbnail. **Still needs shooting** — the rest are in `docs/images/`.
2. Stencil hooked on a plywood corner (`docs/images/tracing.jpg`)
3. The outline traced, stencil flipped for the far corners (`docs/images/traced-outline.jpg`)
4. Both halves pinned together, on the board (`docs/images/stencil-joined.jpg`)
5. Cut and sanded board (`docs/images/sanded-board.jpg`)
6. Rola guard track installed on the underside (`docs/images/rola-installed.jpg`)
7. Render of all four corners covered (`docs/images/board_preview.png`)
8. The cut-line dimension diagram (`docs/images/cutline_diagram.png`)
9. Print layout render (`docs/images/print_layout.png`)

<!-- MakerWorld weights the first image heavily in the feed. A real photo of a
     finished wooden board will out-perform a render every time — lead with it,
     and keep the renders for slots 5-7. -->

---

## Before you publish

- MakerWorld's licence selector: pick **CC BY-SA** to match the repo.
- The stand is a **derivative of dtxtr's model**, not your own design. Before
  you upload it, check his licence actually permits derivatives and
  redistribution, and match the terms he set. If it doesn't, drop the stand from
  the listing and link to his page instead — the stencil stands on its own, and
  an unlicensed remix is the fastest way to get a listing pulled.
- Credit him in the description *and* in MakerWorld's "remix / derivative"
  field, not just in the body text.
- If you enter it in a MakerWorld contest, check the rules on derivative
  works — a jig for someone else's model is usually fine, but the entry terms
  are worth a read.

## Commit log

2026-07-31 Brium Board: parametric OpenSCAD balance board layout stencil, STLs and build guide
    [brium_stencil.scad, brium_stencil_end.stl, brium_stencil_mid.stl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]
2026-07-31 Add brand assets, remixed stand files and logo header
    Brand kit under brand/ — logo, board-outline SVGs at five stroke weights,
    earlier mark/avatar exploration and the generator script. README now leads
    with the logo.
    Adds stl/brium_stand.stl and brium_stand.3mf, a remix of dtxtr's stand, with
    the stand and ball guard sections split and the licence note updated to
    reflect that the stand is a derivative rather than a link-out.
    [brium_stand.3mf, brium_stand.stl]
2026-08-06 Add build photos to the guide
    Nine cleaned-up build photos (resized, contrast-corrected, EXIF-stripped)
    wired into the README steps: materials, cut layout, lip-down registration,
    tracing, traced outline, joined halves, sanded board, and the Rola guard
    hardware and install. MakerWorld photo list updated to point at the real
    files; hero shot placeholder commented out until it's taken.
    Also rides along: whitespring/third_party credits, the beginner-vs-advanced
    ball table, and the real GitHub username in both docs.
